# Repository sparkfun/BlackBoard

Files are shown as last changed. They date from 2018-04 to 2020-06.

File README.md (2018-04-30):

SparkFun BlackBoard
============================

[SparkFun RedBoard  
*SparkFun BlackBoard (SPX-14669)*](https://www.sparkfun.com/products/14669)

The BlackBoard from SparkFun is everything you need in an Arduino Uno with *many* extra perks. BlackBoard has all of the hardware peripherals you know and love: 14 Digital I/O pins with 6 PWM pins, 6 Analog Inputs, UART, SPI and external interrupts. BlackBoard even has an SMD ISP header to connect SPI pins to shields.

We've applied every lesson we've learned about making a better Uno and created the BlackBoard. The USB to serial is now done with the ubiquitous CH340G requiring fewer driver installs and a rock solid microB connector with through hole anchoring. The power portion of the BlackBoard has been reworked: we upgraded the 3.3V regulator to provide up to 600mA, with full thermal and reverse circuit protection, and added extra decoupling capacitance to increase the sensitivity of the ADC readings. We've decreased the brightness of the power, 13, and TX/RX LEDs from blinding to just perfect. We've added 3.3V voltage translation and a [Qwiic connector](https://www.sparkfun.com/qwiic) to the edge of the board to allow for quick and seamless connection to our ever-growing line of I<sup>2</sup>C based [Qwiic](https://www.sparkfun.com/qwiic) products. 

And for more advanced users we've added a 3.3V/5V I/O jumper. Cut the trace to 5V and solder a jumper to the 3.3V side and the board will run at 3.3V. This is extremely handy if you have a shield or 3.3V sensitive devices, such as an SPI interface, that needs protecting.

The SparkFun BlackBoard comes fully tested with the Optiboot bootloader and can be easily programmed with the 'Arduino/Genuino Uno' option from within Arduino. You can power the BlackBoard over USB or through the barrel jack. The on-board power regulator can handle anything from 7 to 15VDC. Check out the related items below for a compatible wall-wart power supply.

Not sure which Arduino or Arduino-compatible board is right for you? Check out our [Arduino Buying Guide](https://www.sparkfun.com/arduino_guide)!

Repository Contents
-------------------
* **/Documentation** - Data sheets, additional product information
* **/Hardware** - Eagle design files (.brd, .sch)

License Information
-------------------

This product is _**open source**_! 

Please review the LICENSE.md file for license information. 

If you have any questions or concerns on licensing, please contact techsupport@sparkfun.com.

Please use, reuse, and modify these files as you see fit. Please maintain attribution to SparkFun Electronics and release any derivative under the same license.

Distributed as-is; no warranty is given.

- Your friends at SparkFun.

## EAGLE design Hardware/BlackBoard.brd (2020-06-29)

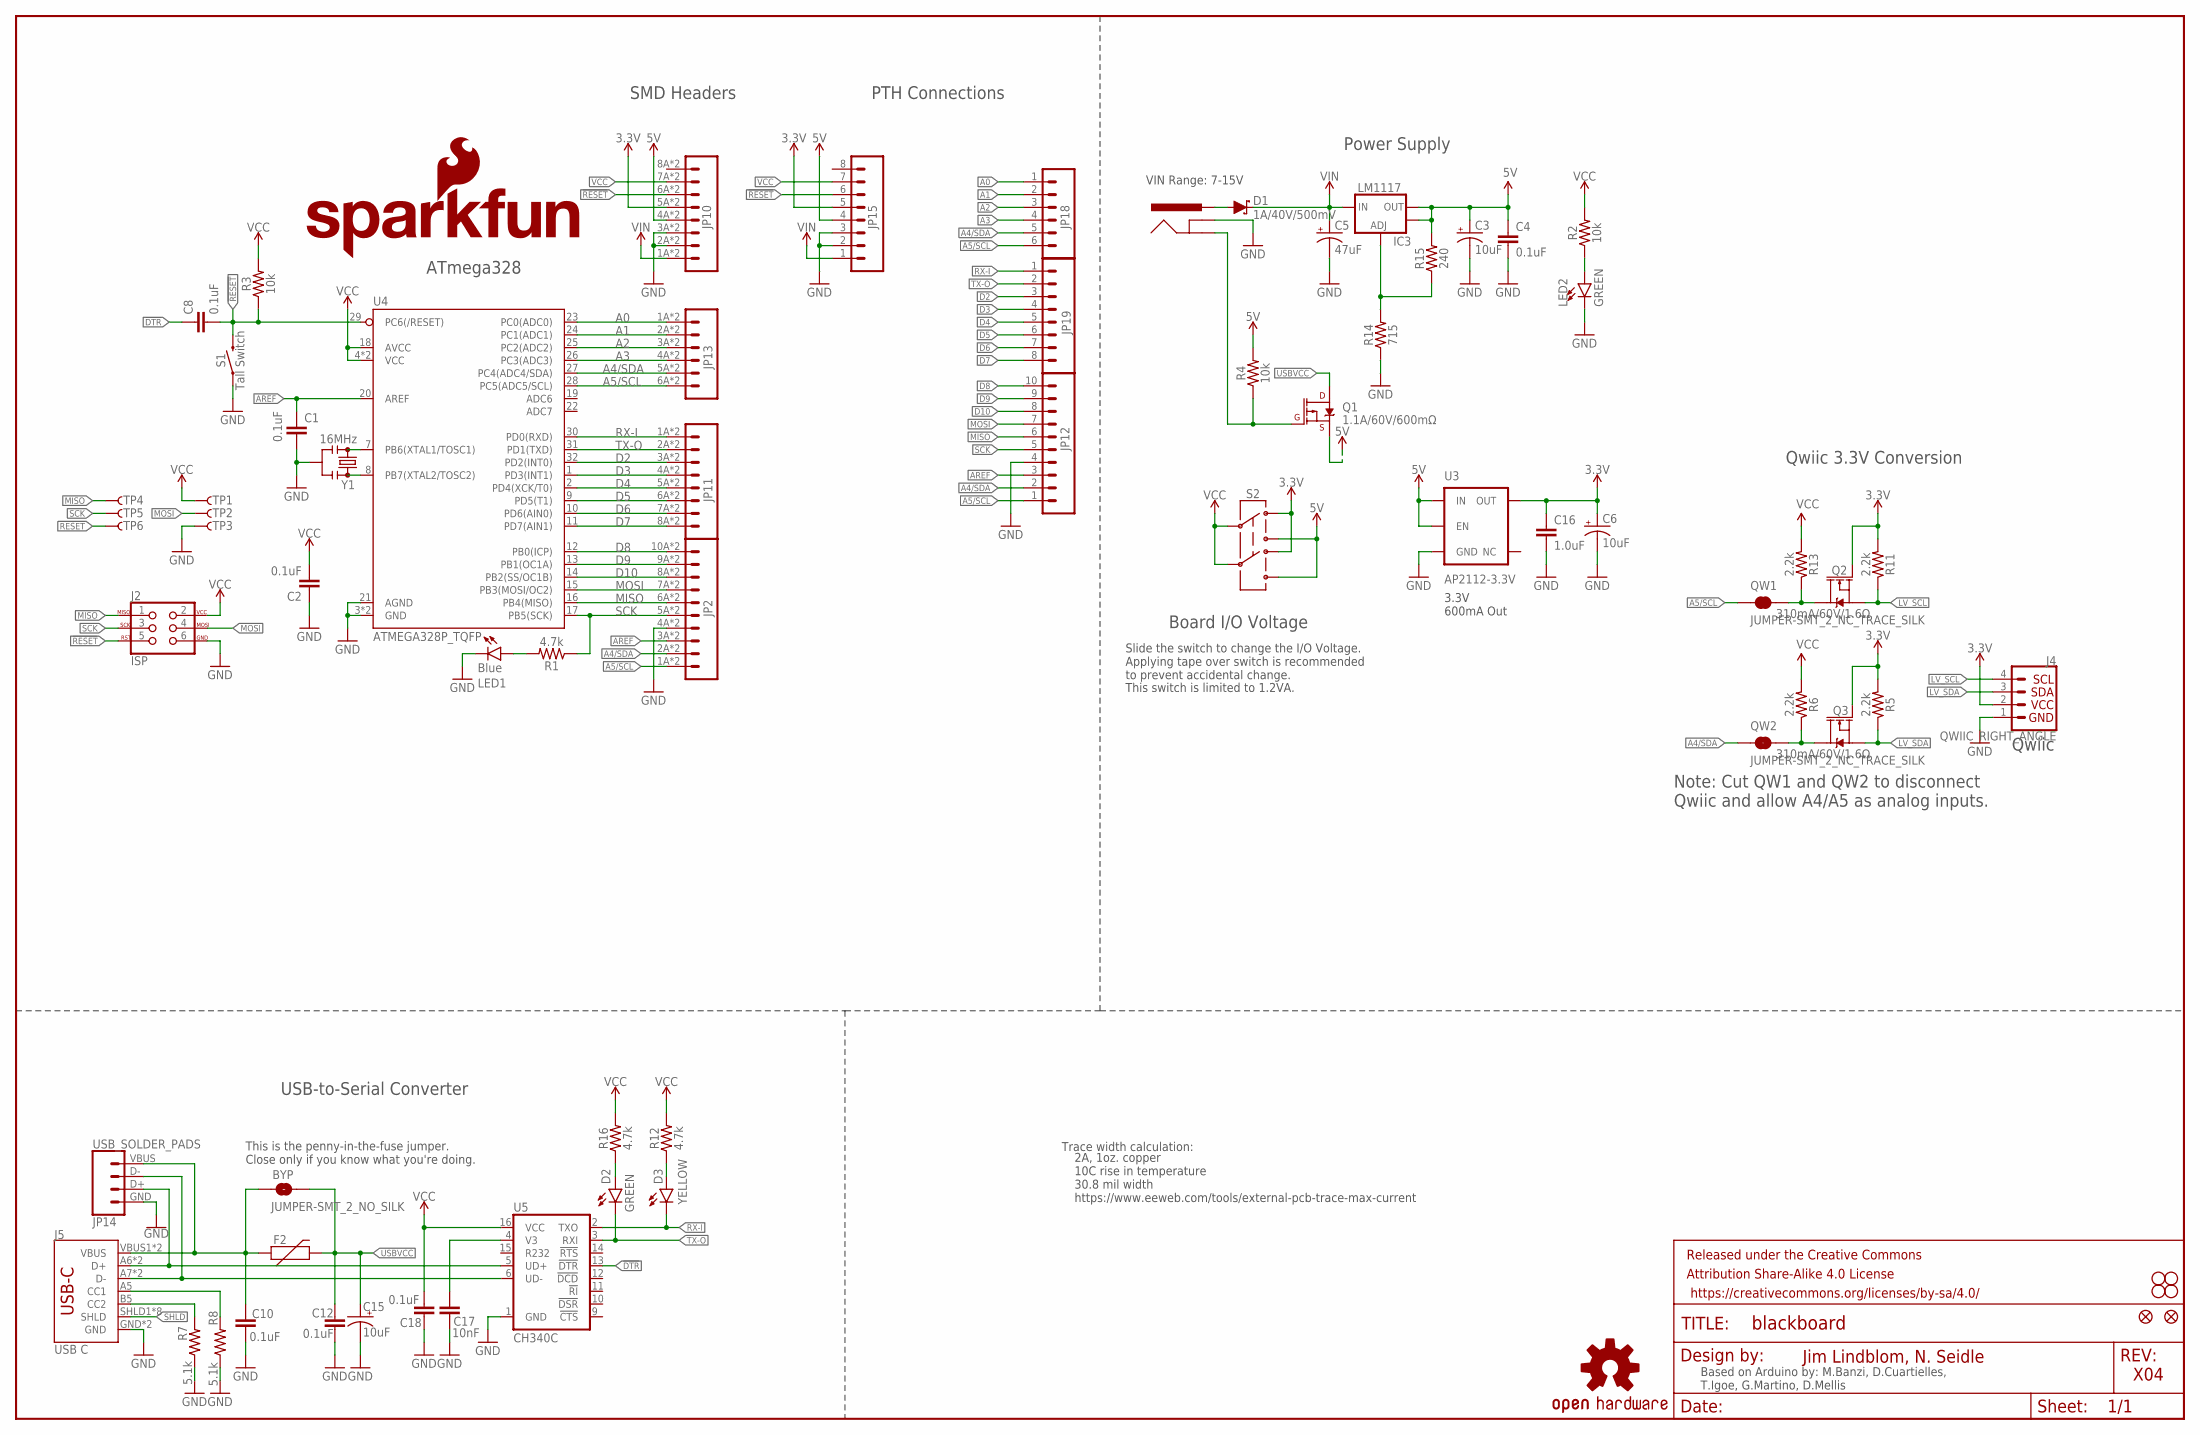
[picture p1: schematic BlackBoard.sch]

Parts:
BYP: JUMPER-SMT_2_NO_SILK; SMT-JUMPER_2_NO_SILK
C1, C2, C4, C8, C10, C12, C18: 0.1uF; 0603
C3, C6, C15: 10uF; EIA3216
C5: 47uF; PANASONIC_D
C16: 1.0uF; 0603
C17: 10nF; 0603
D1: 1A/40V/500mV; SMA-DIODE
D2: GREEN; LED-1206
D3: YELLOW; LED-1206-HIDDENSILK
F2: 6V/2A; 1210
FRAME1: FRAME-LEDGER; CREATIVE_COMMONS
IC3: LM1117; SOT223-ALT1
J2: ISP; 2X3_SMT_POSTS
J3: POWER_JACKSUPER_BOMB_DIGITY; POWER_JACK_SMD_OVERPASTE_SUPER_BOMB_DIGITY
J4: QWIIC_RIGHT_ANGLE; JST04_1MM_RA
J5: USB C; USB-C-16P
JP1: SFE_LOGO_NAME.1_INCH; SFE_LOGO_NAME_.1
JP2: M10SMD_COMBO; 1X10_SMD_COMBINED
JP3, JP4, JP5, JP6: STAND-OFF
JP7: SFE_LOGO_FLAME.1_INCH; SFE_LOGO_FLAME_.1
JP8, JP9: FIDUCIAL1X2; FIDUCIAL-1X2
JP10: M08SMD-COMBO; 1X08_SMD_COMBINED@1
JP11: JP11; 1X08_SMD_COMBINED@1
JP12: M10NO_SILK; 1X10_NO_SILK
JP13: M06SMD-STRAIGHT-COMBO; 1X06_SMD_STRAIGHT_COMBO
JP14: USB_SOLDER_PADS; USB-SOLDER-PADS
JP15: M08NO_SILK; 1X08_NO_SILK@1
JP18: M06NO_SILK; 1X06_NO_SILK@1
JP19: CONN_08NO_SILK_FEMALE_PTH; 1X08_NO_SILK
LED1: Blue; LED-1206-HIDDENSILK
LED2: GREEN; LED-1206
Q1: 1.1A/60V/600mΩ; SOT23-3
Q2, Q3: 310mA/60V/1.6Ω; SOT323
QW1, QW2: JUMPER-SMT_2_NC_TRACE_SILK; SMT-JUMPER_2_NC_TRACE_SILK
R1, R12, R16: 4.7k; 0603
R2, R3, R4: 10k; 0603
R5, R6, R11, R13: 2.2k; 0603
R7, R8: 5.1k; 0603
R14: 715; 0603
R15: 240; 0603
S1: Tall Switch; TACTILE_SWITCH_SMD_5.2MM
S2: SWITCH-DPDT-SMD-AYZ0202; SWITCH_DPDT_SMD_AYZ0202
TP1, TP2, TP3, TP4, TP5, TP6: TP-3x5; PAD.03X.05
U3: AP2112-3.3V; SOT23-5
U4: ATMEGA328P_TQFP; TQFP32-08
U5: CH340C; SO016
U$16: OSHW-LOGOS; OSHW-LOGO-S
Y1: 16MHz; RESONATOR-SMD-3.2X1.3

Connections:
3.3V: C6.+, C16.1, J4.2, JP10.5A (5), JP10.5B (5), JP15.5, Q2.1 (G), Q3.1 (G), R5.2, R11.2, S2.1, S2.4, U3.5 (OUT)
5V: C3.+, C4.1, IC3.2 (OUT), IC3.4 (OUT), JP10.4A (4), JP10.4B (4), JP15.4, Q1.2 (S), R4.2, R15.2, S2.3, S2.6, U3.1 (IN), U3.3 (EN)
!DTR: C8.1, U5.13 (!DTR)
!RESET: C8.2, J2.5, JP10.6A (6), JP10.6B (6), JP15.6, R3.1, S1.3 (2), S1.4 (2), TP6.P$1, U4.29 (PC6(/RESET))
A0: JP13.1A (1), JP13.1B (1), JP18.1, U4.23 (PC0(ADC0))
A1: JP13.2A (2), JP13.2B (2), JP18.2, U4.24 (PC1(ADC1))
A2: JP13.3A (3), JP13.3B (3), JP18.3, U4.25 (PC2(ADC2))
A3: JP13.4A (4), JP13.4B (4), JP18.4, U4.26 (PC3(ADC3))
A4/SDA: JP2.2A (2), JP2.2B (2), JP12.2, JP13.5A (5), JP13.5B (5), JP18.5, QW2.1, U4.27 (PC4(ADC4/SDA))
A5/SCL: JP2.1A (1), JP2.1B (1), JP12.1, JP13.6A (6), JP13.6B (6), JP18.6, QW1.1, U4.28 (PC5(ADC5/SCL))
AREF: C1.1, JP2.3A (3), JP2.3B (3), JP12.3, U4.20 (AREF)
CC1: J5.A5 (CC1), R8.2
CC2: J5.B5 (CC2), R7.2
D2: JP11.3A (3), JP11.3B (3), JP19.3, U4.32 (PD2(INT0))
D3: JP11.4A (4), JP11.4B (4), JP19.4, U4.1 (PD3(INT1))
D4: JP11.5A (5), JP11.5B (5), JP19.5, U4.2 (PD4(XCK/T0))
D5: JP11.6A (6), JP11.6B (6), JP19.6, U4.9 (PD5(T1))
D6: JP11.7A (7), JP11.7B (7), JP19.7, U4.10 (PD6(AIN0))
D7: JP11.8A (8), JP11.8B (8), JP19.8, U4.11 (PD7(AIN1))
D8: JP2.10A (10), JP2.10B (10), JP12.10, U4.12 (PB0(ICP))
D9: JP2.9A (9), JP2.9B (9), JP12.9, U4.13 (PB1(OC1A))
D10: JP2.8A (8), JP2.8B (8), JP12.8, U4.14 (PB2(SS/OC1B))
D+: J5.A6 (D+), J5.B6 (D+), JP14.D+ (3), U5.5 (UD+)
D-: J5.A7 (D-), J5.B7 (D-), JP14.D- (2), U5.6 (UD-)
GND: C1.2, C2.1, C3.-, C4.2, C5.-, C6.-, C10.2, C12.2, C15.-, C16.2, C17.2, C18.2, J2.6, J3.GND (GNDBREAK), J4.1, J5.GND, J5.GND2 (GND), JP2.4A (4), JP2.4B (4), JP10.2A (2), JP10.2B (2), JP10.3A (3), JP10.3B (3), JP12.4, JP14.GND (4), JP15.2, JP15.3, LED1.C, LED2.C, R7.1, R8.1, R14.1, S1.1, S1.2 (1), TP3.P$1, U3.2 (GND), U4.3 (GND), U4.5 (GND), U4.21 (AGND), U5.1 (GND), Y1.2
INSERT: J3.P$4 (GND), Q1.1 (G), R4.1
LV_SCL: J4.4, Q2.2 (S), R11.1
LV_SDA: J4.3, Q3.2 (S), R5.1
MISO: J2.1, JP2.6A (6), JP2.6B (6), JP12.6, TP4.P$1, U4.16 (PB4(MISO))
MOSI: J2.4, JP2.7A (7), JP2.7B (7), JP12.7, TP2.P$1, U4.15 (PB3(MOSI/OC2))
unnamed: LED1.A, R1.2
unnamed: LED2.A, R2.1
unnamed: U4.7 (PB6(XTAL1/TOSC1)), Y1.1
unnamed: U4.8 (PB7(XTAL2/TOSC2)), Y1.3
unnamed: D2.A, R16.1
unnamed: C17.1, U5.4 (V3)
unnamed: Q2.3 (D), QW1.2, R13.1
unnamed: D3.A, R12.1
unnamed: IC3.1 (ADJ), R14.2, R15.1
unnamed: Q3.3 (D), QW2.2, R6.1
PWRIN: D1.A, J3.VIN0 (PWR)
RX-I: D3.C, JP11.1A (1), JP11.1B (1), JP19.1, U4.30 (PD0(RXD)), U5.2 (TXO)
SCK: J2.3, JP2.5A (5), JP2.5B (5), JP12.5, R1.1, TP5.P$1, U4.17 (PB5(SCK))
SHLD: J5.SHLD1 (SHLD), J5.SHLD2 (SHLD), J5.SHLD3 (SHLD), J5.SHLD4 (SHLD), J5.SHLD5 (SHLD), J5.SHLD6 (SHLD), J5.SHLD7 (SHLD), J5.SHLD8 (SHLD)
TX-O: D2.C, JP11.2A (2), JP11.2B (2), JP19.2, U4.31 (PD1(TXD)), U5.3 (RXI)
USBVCC: BYP.2, C12.1, C15.+, F2.2, Q1.3 (D)
VCC: C2.2, C18.1, J2.2, JP10.7A (7), JP10.7B (7), JP15.7, R2.2, R3.2, R6.2, R12.2, R13.2, R16.2, S2.2, S2.5, TP1.P$1, U4.4 (VCC), U4.6 (VCC), U4.18 (AVCC), U5.16 (VCC)
VIN: C5.+, D1.C, IC3.3 (IN), JP10.1A (1), JP10.1B (1), JP15.1
VUSB: BYP.1, C10.1, F2.1, J5.VBUS1 (VBUS), J5.VBUS2 (VBUS), JP14.VBUS (1)

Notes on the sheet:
Power Supply
ATmega328
USB-to-Serial Converter
Based on Arduino by: M.Banzi, D.Cuartielles, T.Igoe, G.Martino, D.Mellis
Jim Lindblom, N. Seidle
X04
VIN Range: 7-15V
3.3V 600mA Out
Board I/O Voltage
Slide the switch to change the I/O Voltage. Applying tape over switch is recommended to prevent accidental change.
Qwiic
Qwiic 3.3V Conversion
Note: Cut QW1 and QW2 to disconnect Qwiic and allow A4/A5 as analog inputs.
This is the penny-in-the-fuse jumper. Close only if you know what you're doing.
Trace width calculation:
2A, 1oz. copper 10C rise in temperature 30.8 mil width https://www.eeweb.com/tools/external-pcb-trace-max-current
This switch is limited to 1.2VA.
PTH Connections
SMD Headers

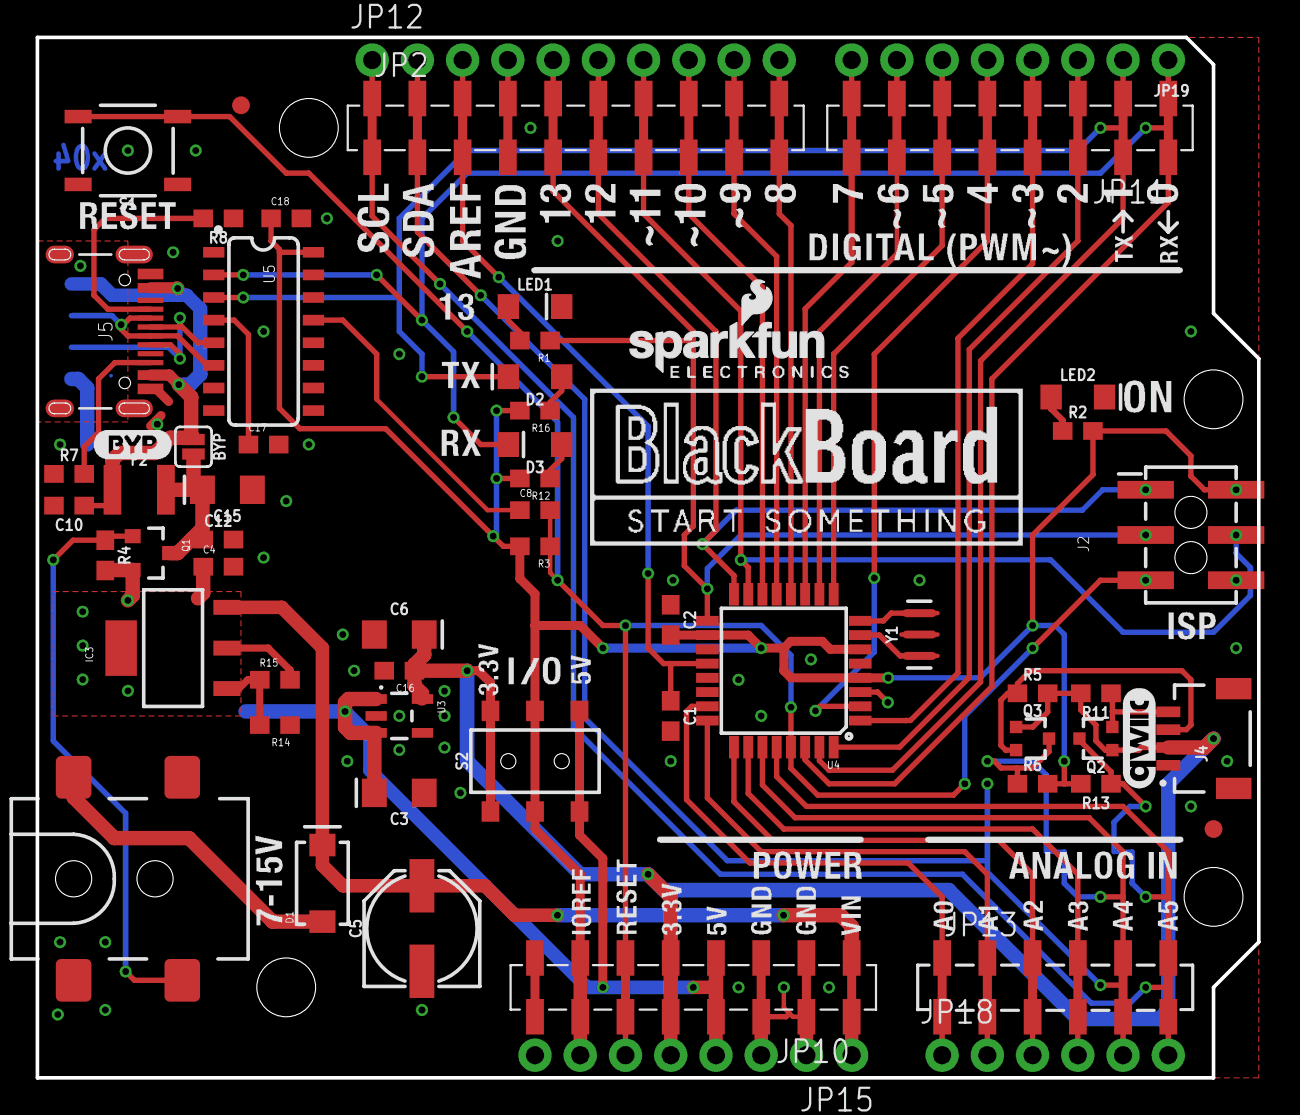
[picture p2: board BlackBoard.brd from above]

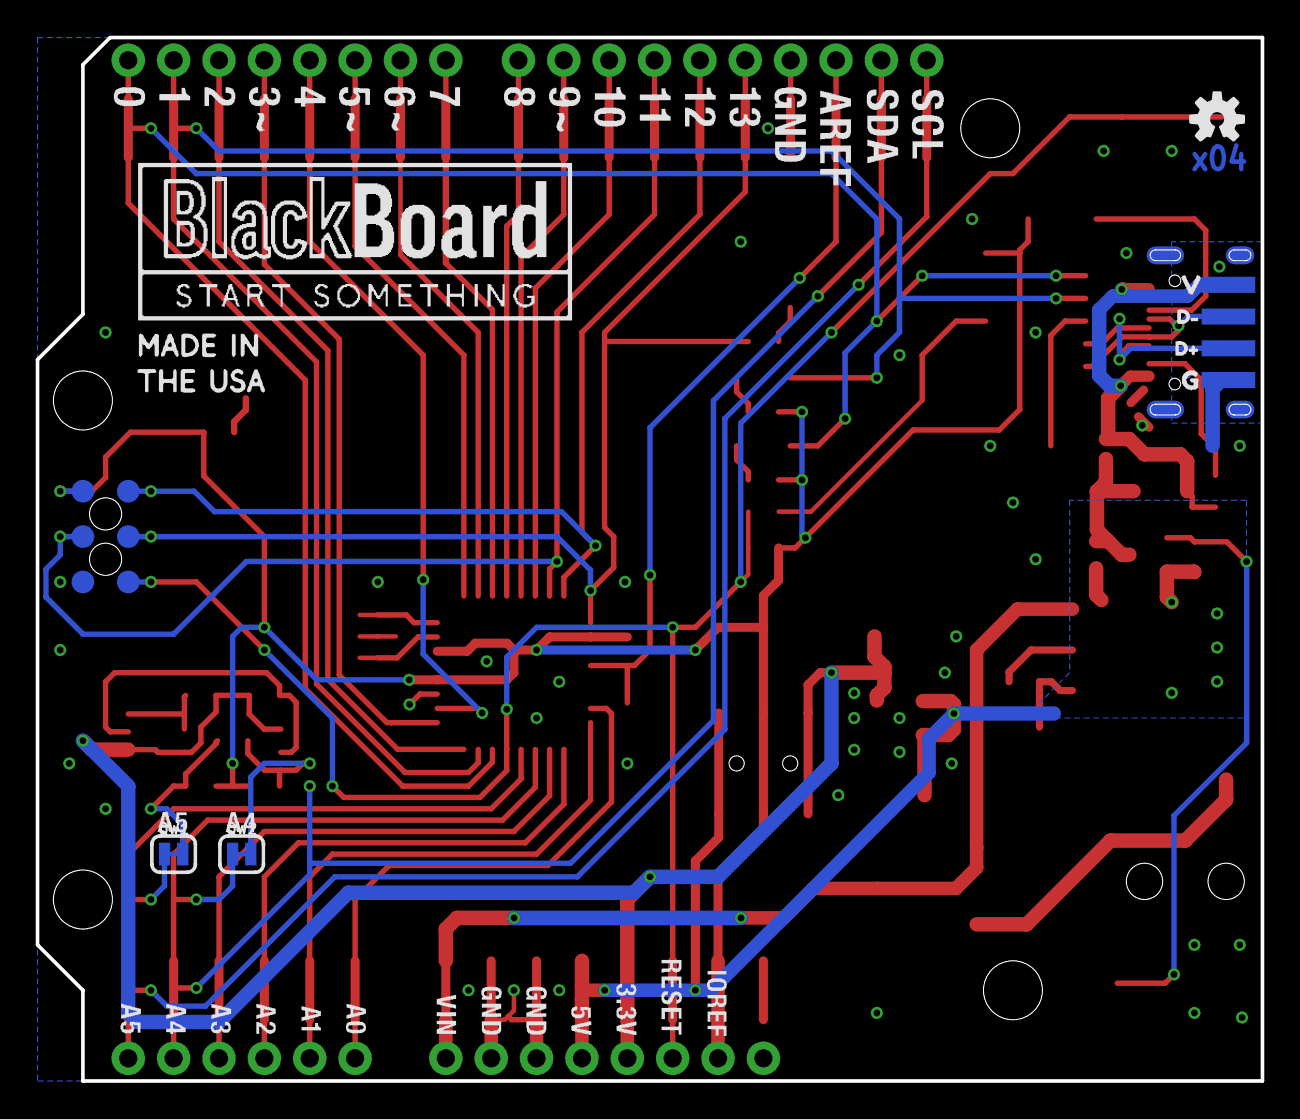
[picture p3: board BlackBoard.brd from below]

Board: 2 copper layers, 68.6 x 58.4 mm, 84 parts (16 on the bottom side), 49 nets.

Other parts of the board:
U$1, U$3: BLACKBOARDLOGO#PNG
U$2: D#3
U$4: MADEINUSA#PNG
U$9: QWIIC_COPYRIGHT_SMALL
U$10: D#4
U$11: G1
U$12: V0
U$68: BYP0

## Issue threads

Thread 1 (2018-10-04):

Adding I2C cut away jumper

nseidle, 2018-10-04:
The Qwiic connector currently puts two 2.2k resistors on A4/A5. This pretty much defeats the analog capabilities of these pins. A cut away jumper (NC-Trace) or an open jumper may fix it. TBD on the next rev.

nseidle, 2019-01-02:
This has been added to x02.

Closed 2019-01-02.

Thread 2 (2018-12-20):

Connect IOREF to VCC

nseidle, 2018-12-20:
So that IOREF pin is whatever the I/O jumper is set to (5V or 3.3V)

nseidle, 2019-06-26:
Fixed on [x03](https://www.sparkfun.com/products/15296).

Closed 2019-06-26.

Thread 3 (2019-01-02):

Increase Fuse Size

nseidle, 2019-01-02:
Possibly up to 2A

nseidle, 2019-01-02:
Consider adding a jumper to 'penny' the fuse.

nseidle, 2019-06-26:
Fixed on [x03](https://www.sparkfun.com/products/15296).

Closed 2019-06-26.

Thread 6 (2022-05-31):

programming guide

fjremnav, 2022-05-31:
There is no documentation in this repository. Do you know where I can find a programming guide?

Thanks,

nseidle, 2022-05-31:
Sorry for the confusion. This board went red. You can read the RedBoard Plus Hookup Guide [here](https://learn.sparkfun.com/tutorials/redboard-plus-hookup-guide).

fjremnav, 2022-05-31:
I don't understand your response. I just ordered a blackboard yesterday and
you tell me it went red.

Fc

On Tue, May 31, 2022, 8:21 AM Nathan Seidle ***@***.***>
wrote:

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

nseidle, 2022-05-31:
My apologies. The [BlackBoard](https://www.sparkfun.com/products/16282) has done well. So well, SparkFun decided to take the design and begin producing it regularly. The latest outcome of that is the [RedBoard Plus](https://www.sparkfun.com/products/18158). The BlackBoard and the RedBoard Plus are nearly identical. One of the main differences is that SparkX products almost never get documentation beyond the schematic, and an Arduino library (where applicable). In the case of the BlackBoard, there is no hookup guide or detailed information other than the schematic. Lucky for you, the BlackBoard 'went red', meaning the RedBoard Plus was created, and as such you can read the [RedBoard Plus hookup guide](https://learn.sparkfun.com/tutorials/redboard-plus-hookup-guide) for information about the specific pieces of hardware on the RedBoard, and infer those same features on its parent (and influence) the BlackBoard.

We continue to sell the BlackBoard as it is our sandbox. We modify the design as users recommend and request changes, and we can do so easily because it does *not* have documentation. Its design is always in flux.

I hope that makes a bit more sense.

fjremnav, 2022-06-06:
Nathan

   I received blackboard C today and connect to my PC. Use sketch SW to
program it. Sketch asks me which arduino board is.
Is this blackboard C  Arduino nano or uno or something else?

FC

On Tue, 31 May 2022 at 10:18, Nathan Seidle ***@***.***>
wrote:

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

Closed 2022-05-31.

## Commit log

2018-04-30 Small schematic changes
    [BlackBoard.brd, BlackBoard.sch]
2018-04-30 Readme update. Schematic compression.
    [BlackBoard.brd, BlackBoard.sch]
2018-11-19 Add USB pads for external connector
    [BlackBoard.brd]
2018-11-19 Removing old gerbers. Adding production panel.
    [BlackBoard-Panel.GBL, BlackBoard-Panel.GBO, BlackBoard-Panel.GBS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]
2019-01-10 Cleanup for release of v2
    [BlackBoard.brd, BlackBoard.sch]
2019-02-21 Swap to larger PTC. Correct connection to IOREF.
    [BlackBoard.brd, BlackBoard.sch]
2019-03-13 Adding panel
    [BlackBoard-Panel.GBL, BlackBoard-Panel.GBO, BlackBoard-Panel.GBS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]
2020-01-27 Add switch for IO voltage. Add PTH holes.
    [BlackBoard.brd, BlackBoard.sch]
2020-01-27 Adjust silk on PTH headers
    [BlackBoard.brd]
2020-01-27 Add panel files
    [BlackBoard-Panel.GBL, BlackBoard-Panel.GBO, BlackBoard-Panel.GBP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]

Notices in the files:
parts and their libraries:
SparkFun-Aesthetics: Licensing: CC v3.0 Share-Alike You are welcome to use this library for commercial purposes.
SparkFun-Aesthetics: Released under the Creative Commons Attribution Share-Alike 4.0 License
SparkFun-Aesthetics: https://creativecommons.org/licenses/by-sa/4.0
